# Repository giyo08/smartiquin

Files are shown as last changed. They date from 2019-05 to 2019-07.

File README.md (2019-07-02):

# Smartiquín
Proyecto para la cátedra SOA de la UNLaM

**Integrantes**

  * Alberto, Gisele Romina	   	34.154.196
  * Benítez, Gerardo Abel		    25.883.409
  * Coradini, Gonzalo Fabián		38.946.395
  * Vázquez, Lucia Maité	    	40.886.803

**Descripción**

Smartiquín es un botiquín de madera que te facilita la gestión de los medicamentos que estás tomando: ya que mantendrá un registro de los medicamentos, descontando la cantidad que se ingiere, te respalda diciendote si falta algún medicamento y te informará si hay demasiada humedad o luz dentro. Para todo esto, Smartiquín estará conectado a una aplicación móvil, en donde se podrá ver los datos de los medicamentos con los que se cuenta actualmente en el botiquín y las cantidades pertinentes. En la misma, se recibirán una serie de notificaciones para que el usuario esté informado en tiempo real del estado de sus medicamentos; las mismas notifican:
  * Cuando hay luz dentro del botiquín estando la puerta cerrada.
  * Cuando hay humedad en el mismo.
  * Cuando un medicamento está vencido.
  * Cuando de un medicamento hay pocas pastillas.
  * Cuando de un medicamento no hay más pastillas.
Además, el sistema cuenta con una apertura supervisada y segura: necesitarás la aplicación móvil para pedir que el botiquín se destrabe y puedas acceder a su contenido (necesitarás también la aplicación para hacer el bloqueo); de ésta forma, se restringe el acceso a los medicamentos al usuario de la aplicación, manteniéndolos fuera del alcance de los niños.

**Hardware a utilizar**

  * *Arduino UNO R3
  * *Protoboard de 150 puntos
  * *Sensor de humedad DHT11
  * *3 Switch fin de carrera
  * *Fotoresistor LDR
  * *Luces LED
  * *Módulo Bluetooth HC-05
  * *Buzzer activo
  * *Electroimán 12v
  * *Relay
  * *Cargador 5v
  * *Cargador 12v
  * *Cables de conexión
  * *Resistencias

**Software Utilizado**

Arduino IDE 1.8.9
Android Studio 3.4.1

**Descripción de la implementación**

El arduino y la aplicación móvil se comunicarán mediante bluetooth. En este caso utilizamos un módulo bluetooth para el arduino, de modelo HC-05.
Los medicamentos se colocarán arriba de los switchs, con los que se interpretará una ingesta de medicamento (una pastilla). 
El electroimán se mantendrá energizado de forma que trabe la puerta y, al mandarle una señal desde la aplicación, ya sea a través del respectivo botón o habilitando el shake del celular, el arduino desmagnetiza el imán destrabando la puerta. Para facilitar su implementación, utilizamos un relé para la interconexión entre arduino-electroimán.
En el botiquín habrá un sensor de luz y otro de humedad: el primero se colocará en el interior para determinar si dentro del botiquín cerrado hay presencia de luz, de modo que se pueda notificar al usuario cuando el botiquín no esté en condiciones. El segundo se colocará en el interior y se utilizará para efectivizar, cuando la humedad supere cierto valor apto, el envío de una notificación al usuario. Ambos, cuando tomen valores no deseados, activan la reproducción de un sonido de alerta con el buzzer. 
Los leds se dispondrán dos en el frente del botiquín, uno para informar si la puerta está cerrada - rojo- o abierta - verde-, y el restante, en el interior del botiquín para alumbrar el interior del mismo cuando el mismo esté abierto y en el ambiente no haya luz suficiente para ver los medicamentos.

**Manual de usuario**
 * Primeros pasos:

    * *Conexion Android-Smartiquín
    * *El usuario encenderá el Smartiquín.
    * *El usuario descargara e ingresara a la aplicación de Smartiquín en su dispositivo android (*).
    * *Debe permitir el encendido del bluetooth.
    * *A continuación deberá presionar “Conectar con Arduino”.
    * *Luego de unos segundos el Smartiquín estará conectado exitosamente con su dispositivo Android.

	(*) Versión mínima de android : android 6.0 MarshMallow

**Más información en:https://github.com/giyo08/smartiquin/blob/master/Informe-Final/Informe%20Final.pdf**

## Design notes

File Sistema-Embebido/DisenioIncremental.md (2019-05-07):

# Smartiquin: Diseño Incremental
Vamos a describir los diferentes pasos que recorrimos para llegar a la version final de nuestro prototipo

## Version 01: conexión basica, leds y pulsadores
Para la versión inicial vamos a usar como sensores algunos pulsadores, y variables preconfiguradas y como actuadores vamos a usar leds. 
En nuestra configuracion inicial usaremos

### Componentes: 
1. Servo = led rojo
2. Buzzer = Led azul
3. SensorHumedad = Variable
4. SensorLuz = SensorLuz
5. Switch01 = pulsador01
6. Switch02 = pulsador02
7. Switch03 = pulsador03

### Procedimiento 
Conexiones componente a componente
* LedRojo a PinDigital03
* LedAzul a PinDigital04
* Sensor de Luz a PinAnalogico01
* Pulsador01 a PinDigital07
* Pulsador02 a PinDigital08
* Pulsador03 a PinDigital09

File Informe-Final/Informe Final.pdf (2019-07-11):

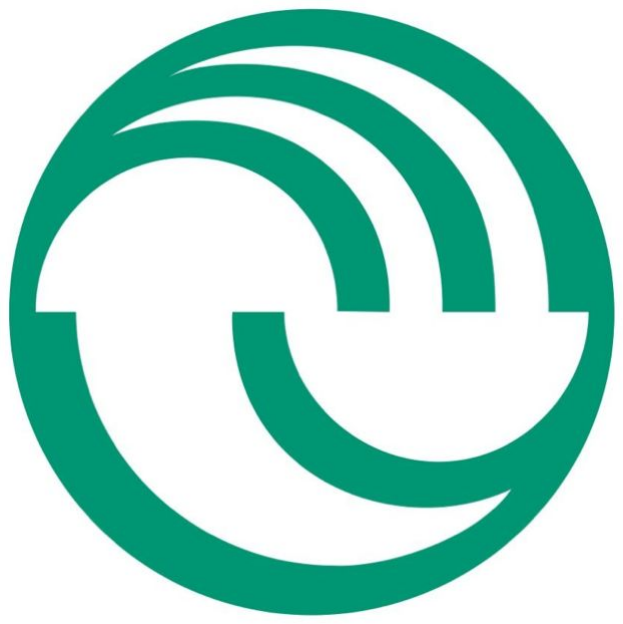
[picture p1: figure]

# UNLaM

# Sistemas Operativos Avanzados

2019

# SMARTIQUIN

## Sistemas Embebidos - Android

Profesores

- Barillaro, Sebastián
- Carnuccio, Esteban
- De Luca, Graciela
- García, Gerardo
- Valiente, Waldo A.
- Volker, Mariano

Integrantes

- Alberto, Gisele Romina | 34.154.196
- Benítez, Gerardo Abel | 25.883.409
- Coradini, Gonzalo Fabián 38.946.395
- Vázquez, Lucía Maité 40.886.803

Smartiquin | Sistemas Operativos Avanzados

Índice de Contenidos

Introducción | 2
Detalle de la Implementación | 2
Descripción | 2
Diseño Incremental | 3
Hardware Utilizado | 3
Software Utilizado | 4
Componentes | 4
Diagramas de bloques | 8
Diagrama de conexión | 10
Manual de usuario | 11
Android | 12
Activities: | 13
Sensores: | 14
Persistencia de datos: | 15
Conexión con el arduino: | 15
Fuentes | 15

## Introducción

Smartiquín es un botiquín de madera que te facilita la gestión de los medicamentos que estás tomando: ya que mantendrá un registro de los medicamentos, descontando la cantidad que se ingiere, te respalda diciendote si falta algún medicamento y te informará si hay demasiada humedad o luz dentro. Para todo esto, Smartiquín estará conectado a una aplicación móvil, en donde se podrá ver los datos de los medicamentos con los que se cuenta actualmente en el botiquín y las cantidades pertinentes. En la misma, se recibirán una serie de notificaciones para que el usuario esté informado en tiempo real del estado de sus medicamentos; las mismas notifican:

- Cuando hay luz dentro del botiquín estando la puerta cerrada.
- Cuando hay humedad en el mismo.
- Cuando un medicamento está vencido.
- Cuando de un medicamento hay pocas pastillas.
- Cuando de un medicamento no hay más pastillas.

Además, el sistema cuenta con una apertura supervisada y segura: necesitarás la aplicación móvil para pedir que el botiquín se destrabe y puedas acceder a su contenido (necesitarás también la aplicación para hacer el bloqueo); de ésta forma, se restringe el acceso a los medicamentos al usuario de la aplicación, manteniéndolos fuera del alcance de los niños.

## Detalle de la Implementación

## Descripción

El arduino y la aplicación móvil se comunicarán mediante bluetooth. En este caso utilizamos un módulo bluetooth para el arduino, de modelo HC-05.

Los medicamentos se colocarán arriba de los switchs, con los que se interpretará una ingesta de medicamento (una pastilla).

El electroimán se mantendrá energizado de forma que trabe la puerta y, al mandarle una señal desde la aplicación, ya sea a través del respectivo botón o habilitando el shake del celular, el arduino desmagnetiza el imán destrabando la puerta. Para facilitar su implementación, utilizamos un relé para la interconexión entre arduino-electroimán.

En el botiquín habrá un sensor de luz y otro de humedad: el primero se colocará en el interior para determinar si dentro del botiquín cerrado hay presencia de luz, de modo que se pueda notificar al usuario cuando el botiquín no esté en condiciones. El segundo se colocará en el interior y se utilizará para efectivizar, cuando la humedad supere cierto valor apto, el envío de una notificación al usuario. Ambos, cuando tomen valores no deseados, activan la reproducción de un sonido de alerta con el buzzer.

Los leds se dispondrán dos en el frente del botiquín, uno para informar si la puerta está cerrada - rojo- o abierta - verde-, y el restante, en el interior del botiquín para alumbrar el interior del mismo cuando el mismo esté abierto y en el ambiente no haya luz suficiente para ver los medicamentos.

## Diseño Incremental

Para la primera versión usamos 3 switchs como sensores y 3 leds, rojo, verde y blanco, como actuadores.

En esta etapa implementamos

- Switchs
- Leds

Aquí probamos encender y apagar los leds pulsando los switchs y funciono correctamente.

En un primer incremento añadimos el sensor de humedad DHT11.

En un segundo incremento agregamos un buzzer el cual probamos su funcionamiento con los pulsadores (que ya estaban implementados).

Como tercer incremento, incluímos el fotoresistor (sensor de luz).

A partir de aquí, agregamos al proyecto el electroimán el cual necesitaba un relé para controlarlo junto a una fuente de 12v (para el electroimán) y otra de 5v (para el relé).

Por último agregamos el módulo Bluetooth conectado a la fuente de 5v.

## Hardware Utilizado

Arduino UNO R3

Protoboard de 150 puntos

Sensor de humedad DHT11

3 Switch fin de carrera

Fotoresistor LDR

Luces LED

Módulo Bluetooth HC-05

Buzzer activo

Electroimán 12v

Relay

Cargador 5v

Cargador 12v

Cables de conexión

Resistencias

## Software Utilizado

Arduino IDE 1.8.9

Android Studio 3.4.1

## Componentes

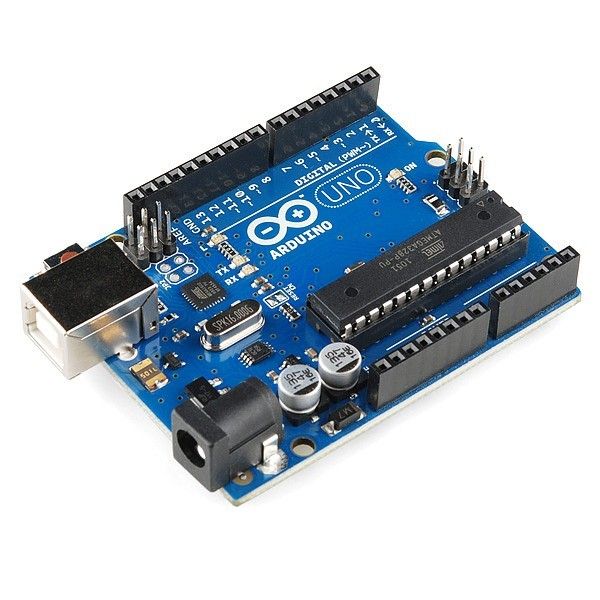
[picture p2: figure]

Arduino Uno

Arduino es una plataforma de prototipos electrónicos de código abierto basada en hardware y software flexibles y fáciles de usar. Arduino puede sentir el entorno mediante la recepción de entradas desde una variedad de sensores y puede afectar a su alrededor mediante el control de luces, motores y otros artefactos. Para programar el microcontrolador se utiliza el lenguaje de programación Arduino (basado en Wiring) y el software arduino (IDE).

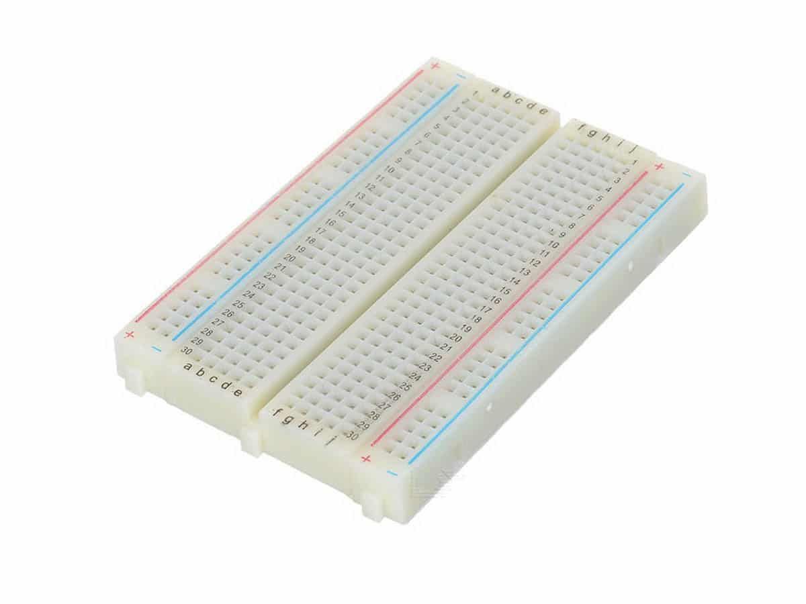
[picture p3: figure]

Protoboard

Tablero con orificios conectados eléctricamente entre sí de manera interna, en el cual se pueden insertar componentes electrónicos y cables para el armado y prototipado de circuitos electrónicos

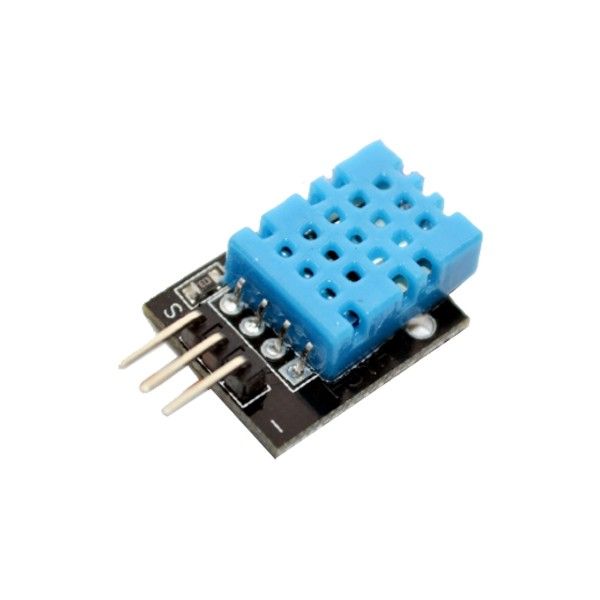
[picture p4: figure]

Sensor de humedad DHT 11

Sensor digital que nos permite medir la humedad relativa y la temperatura.

En Smartiquín es utilizado para medir la humedad dentro del botiquín.

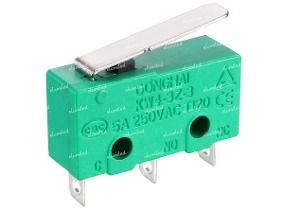
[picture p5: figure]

Switch final de carrera

Es un interruptor eléctrico que se acciona por muy poca fuerza física, a través del uso de un mecanismo de punto de inflexión, a veces llamado mecanismo de sobre-centro.

En Smartiquín es utilizado para controlar la cantidad y el estado de los medicamentos del botiquín.

Fotoresistor LDR

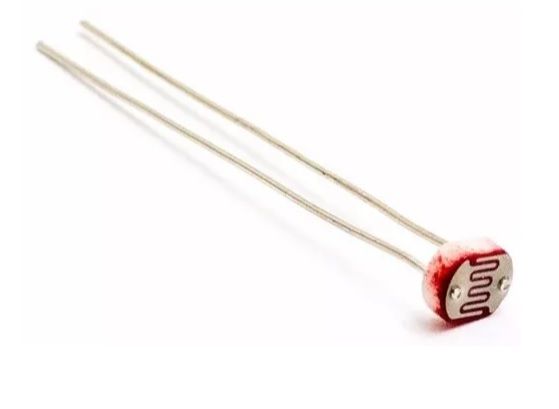
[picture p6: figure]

Componente cuya resistencia varía en función de la luz que recibe. Cuanto mayor sea la intensidad de luz que incide en la superficie del LDR menor será su resistencia y en cuanto menor sea la luz mayor será la su resistencia.

En Smartiquín es utilizado para comprobar que la luz del interior del botiquín no esté encendida cuando no sea necesario.

Luces led

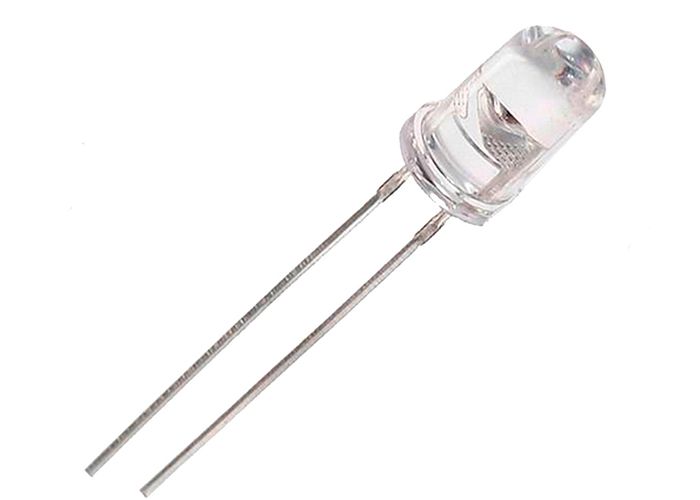
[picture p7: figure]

Es un componente electrónico de dos puntas que permite la circulación de energía a través de él en un solo sentido. Estos diodos LED son semiconductores y, cuando los electrones pasan a través de ellos, se convierten en luz.

En Smartiquín se utilizan para iluminar el botiquín y indicar el estado del botiquín (si se encuentra abierto o cerrado).

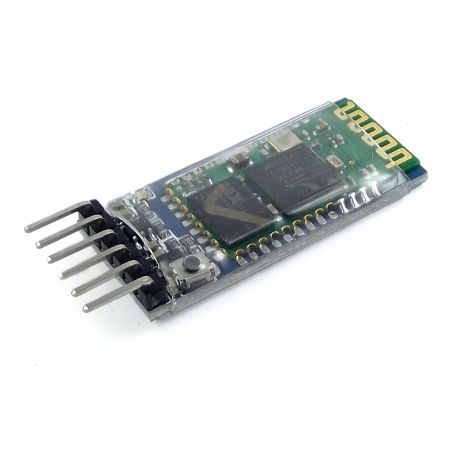
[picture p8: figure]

Módulo Bluetooth HC-05

El módulo bluetooth HC-05 viene configurado de fábrica para trabajar como maestro o esclavo. En el modo maestro puede conectarse con otros módulos bluetooth, mientras que en el modo esclavo queda a la escucha peticiones de conexión.

Este módulo bluetooth nos permite realizar un enlace inalámbrico entre el botiquín y un dispositivo Android, desde el cual controlaremos las características del Smartiquín.

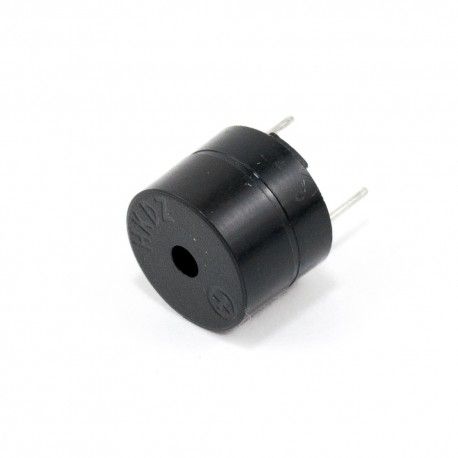
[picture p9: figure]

Buzzer Activo

Es un dispositivo que generan un sonido de una frecuencia determinada y fija cuando son conectados a tensión

En Smartiquín es utilizado para informar al usuario cuando el nivel de humedad del botiquín supera un rango máximo, como de informarle cuando no repuso los medicamentos en el botiquín.

Relay

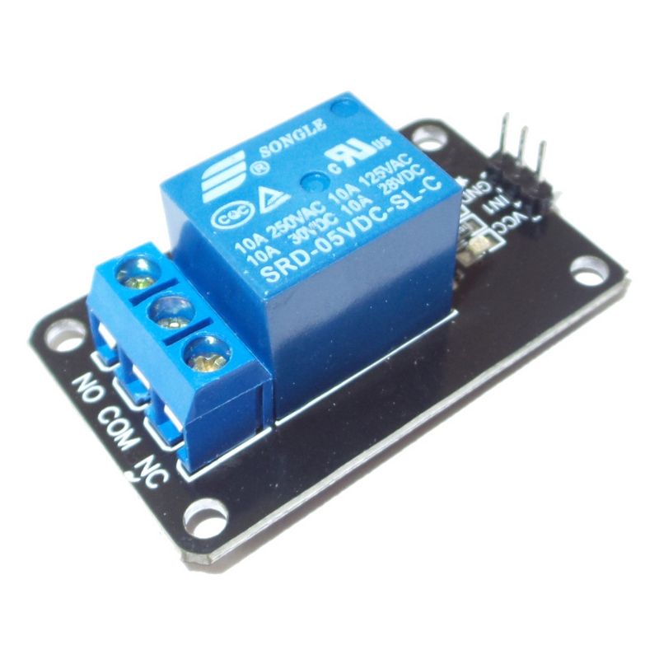
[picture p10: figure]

Dispositivo electrónico que se usa para el control o switcheo de cargas de potencia. Permite controlar el encendido y el apagado de cualquier aparato que se conecte a una fuente de alimentación externa. El relé hace de interruptor y se activa/desactiva mediante una entrada de datos. Gracias a esto se puede controlar el encendido de cualquier aparato.

En Smartiquín es usado junto a un electroimán para controlar el encendido y apagado de este.

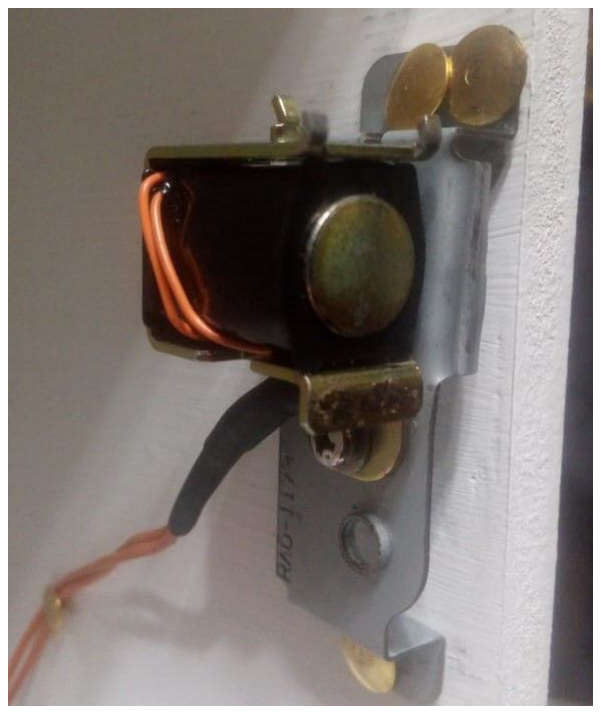
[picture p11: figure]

Electroimán

Dispositivo eléctrico que permite atraer objetos ferromagnéticos mediante el empleo de un campo magnético. Este puede ser encendido y apagado a voluntad, simplemente actuando sobre la corriente suministrada.

En Smartiquín es utilizado, junto a un relé, para bloquear y desbloquear la puerta del botiquín.

## Diagramas de bloques

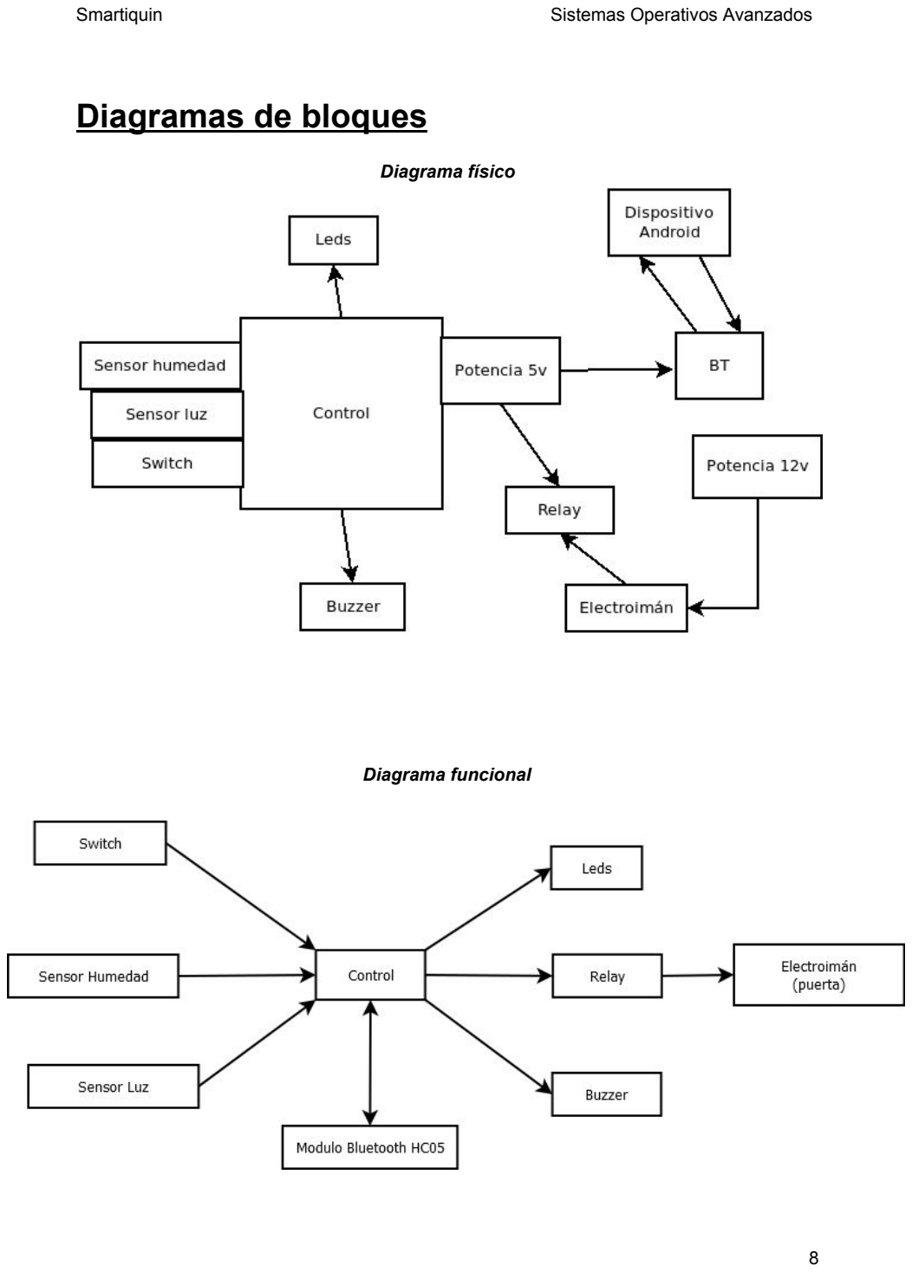
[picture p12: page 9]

Diagrama físico

Diagrama funcional

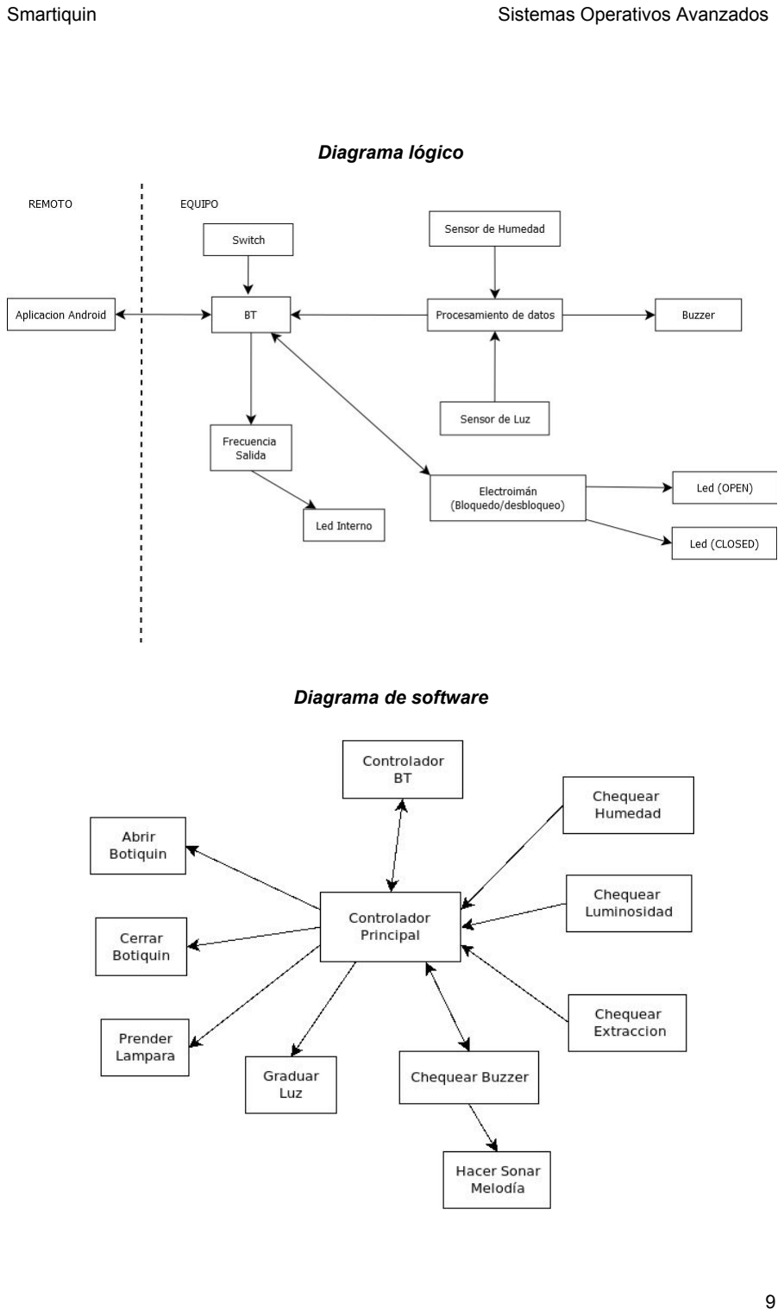
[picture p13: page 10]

Diagrama lógico

Diagrama de software

## Diagrama de conexión

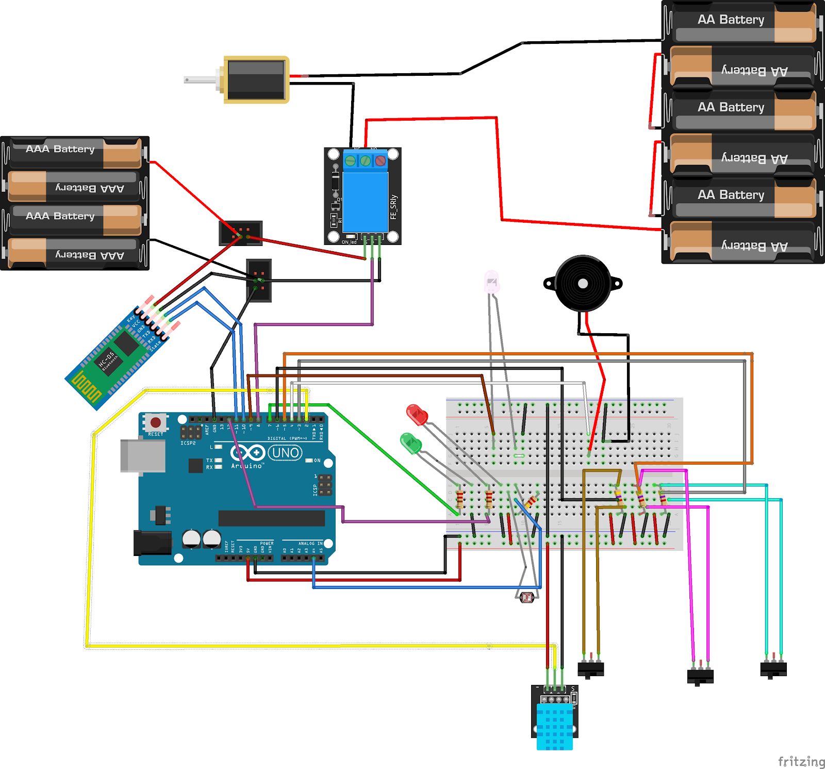
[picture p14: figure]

## Manual de usuario

Primeros pasos:

1) Conexion Android-Smartiquín
- El usuario encenderá el Smartiquín.
- El usuario descargara e ingresara a la aplicación de Smartiquín en su dispositivo android (*).
- Debe permitir el encendido del bluetooth.
- A continuación deberá presionar “Conectar con Arduino”.
- Luego de unos segundos el Smartiquín estará conectado exitosamente con su dispositivo Android.

(*) Versión mínima de android : android 6.0 MarshMallow

Eventos

1. Apertura/Cierre del botiquín
- Desde el dispositivo Android , el usuario deberá presionar el botón Abrir/Cerrar para abrir o cerrar el botiquín.
- Opcionalmente podrá optar por activar la apertura/cierre por shake (Agitar el celular).
- Activando esta opción, el usuario deberá agitar levemente el celular hacia cualquier lado.
- Cuando el movimiento sea considerado como una agitación, el dispositivo emitirá una vibración confirmando que la apertura/cierre del botiquín es correcta.
2. Ingreso de medicamentos
- En el botiquín, el usuario colocará el envase del medicamento en cualquiera de las tres posiciones disponibles (*).
- En la aplicación, el usuario deberá ingresar al registro de
medicamentos y agregar el medicamento colocado en el paso anterior.
- Ingresa al formulario donde ingresara:
- Posicion : Numero de slot en cual se colocó el medicamento.
- Nombre: Nombre del medicamento
- Laboratorio: Nombre del laboratorio del medicamento
- Fecha de Vencimiento: Fecha de caducidad del medicamento. Debe ser una fecha válida entre 2019 y 2039.

- Cantidad de Medicamentos: Cantidad de pastillas que se colocaron en el slot del botiquín.
- Cantidad Mínima: Cantidad límite en la cual se avisará al usuario en que debe reponer el medicamento.
- Una vez completado estos campos, se presiona “Aceptar” y el medicamento quedará registrado.

(*) Nota: Solo se tiene 3 posiciones para colocar el medicamento. Una vez completos estos slots no será posible controlar más medicamentos, aunque estos se encuentren en el botiquín.

3. Humedad elevada
- Al detectarse elevada niveles de humedad en el botiquín, este avisará al usuario encendiendo una alarma.
- Cuando esto ocurra, se activara un sensor de proximidad, de manera que el usuario podrá detener esta alarma acercando la mano al dispositivo android.
4. Luz encendida en el interior del botiquín
- Si ocurre que en el interior del botiquín, estando cerrado, hay presencia de luz, se notificará al usuario.
- Cuando esto ocurra, se activara un sensor de proximidad, de manera que el usuario podrá detener esta alarma acercando la mano al dispositivo android.

## Android

La aplicación en android ofrece una completa interacción y control con los medicamentos que se encontraran en el Smartiquín. Para esto se contará con registros que estarán asociados a los diferentes switch del botiquín. El usuario cargará los registros con la información de los medicamentos (como su nombre, laboratorio, fecha de vencimiento, cantidad de medicamentos), donde una vez registrado podrá ver su información y llevar un control de estos.

## Activities:

La aplicación cuenta con 3 activities las cuales son:

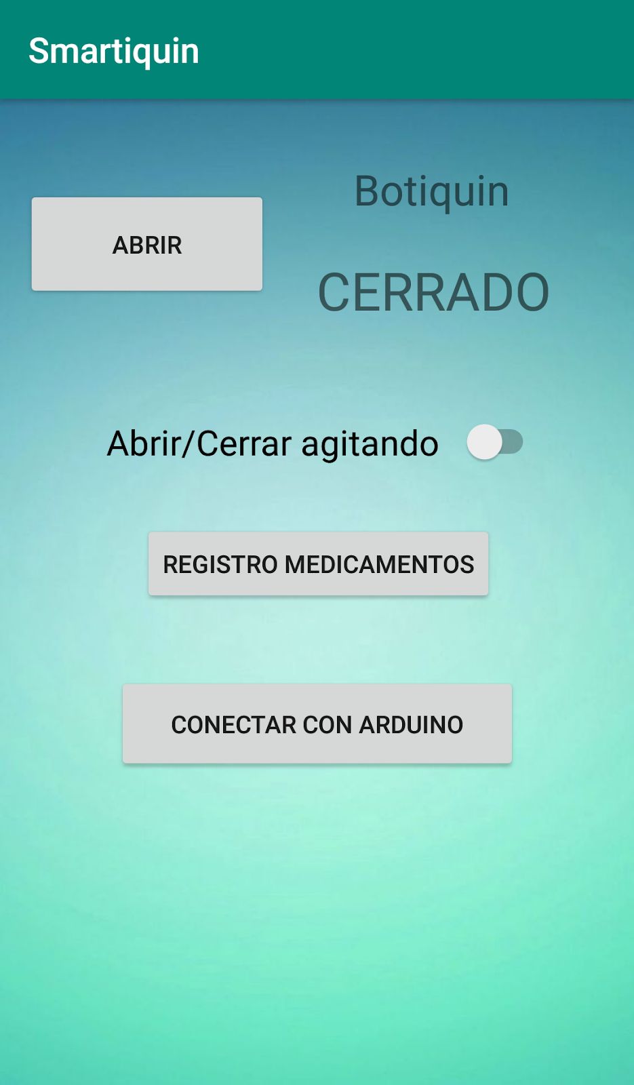
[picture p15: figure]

MainActivity

Activity principal en la cual se tiene las opciones de apertura del botiquín (Con un botón o con un shake), el acceso a los registros de medicamentos y la conexión con el arduino.

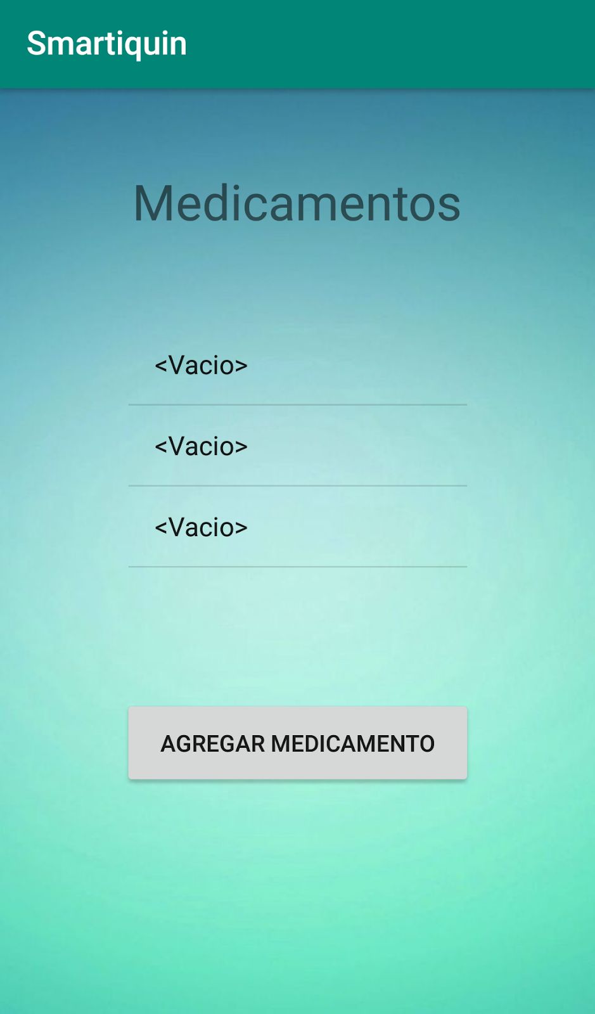
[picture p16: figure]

RegisterActivity

Activity en la cual tendremos la información de los medicamentos registrados que se encuentran en nuestro botiquín. Se podrá ver la información de los medicamentos registrados.

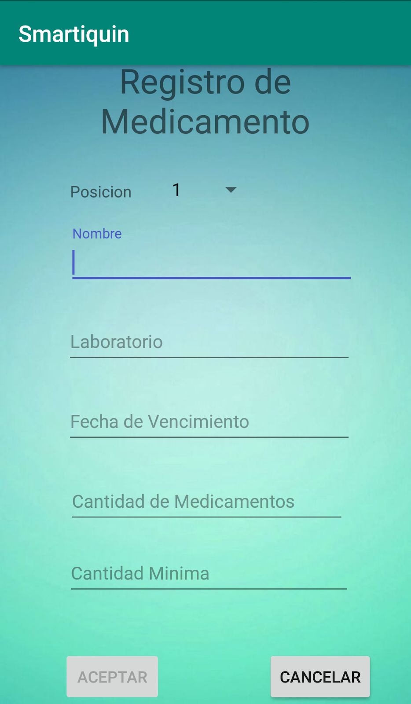
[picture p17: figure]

Form Activity

Activity en la cual se realiza el registro de la información de los medicamentos que se encuentran el botiquín.

## Sensores:

Para el funcionamiento de la aplicación utilizamos los siguientes sensores del dispositivo android:

Acelerómetro
Utilizando el acelerómetro logramos simular un shake con el cual, cuando el usuario active esta función, podrá abrir o cerrar el botiquín solamente agitando levemente el dispositivo android.

Para realizar esto, cuando se detecta un cambio en algunos de los tres ejes del dispositivo (X, Y, Z), verificamos si el valor obtenido sobrepasa un límite prefijado. Si lo hace este movimiento es tomado como una agitación y por lo tanto permite cambiar el estado del botiquín de abierto a cerrado o cerrado a abierto.

Sensor de luz
El sensor es utilizado para captar la luz presente en la habitación al momento de abrir el botiquín, de manera que si hay poca luz en la habitación se encenderá un led, dentro del botiquín, para iluminar su interior.

Sensor de proximidad
El sensor de proximidad entrará en acción al momento en que el buzzer, que se encuentra en el botiquín, comience a sonar debido a los factores a cual esté expuesto. En ese instante el sensor de proximidad se activará y el usuario podrá detener el sonido de alarma del botiquín aproximando la mano hacia el dispositivo android.

## Persistencia de datos:

Para conservar los registros de los medicamentos, ya que estos se perdían cuando la aplicación era detenida o destruida, optamos por elegir SQLite para conservar los datos en una base de datos que se encontrada en cada dispositivo android.

Cada registro es guardado en la base de datos, recuperado y actualizado dependiendo de la necesidad concreta de la aplicación en cada operación que se realice, manteniendo así la persistencia de los datos en nuestra aplicación.

## Conexión con el arduino:

La conexión entre el dispositivo Android y el Smartiquín es realizada mediante Bluetooth. El celular funciona como maestro y se conecta al módulo bluetooth que se encuentra en el arduino.

De esta manera podemos enviar la información necesaria entre el arduino y el dispositivo android.

## Fuentes

Arduino: https://www.arduino.cc/Android: https://developer.android.com/

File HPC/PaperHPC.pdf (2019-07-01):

## Reconocimiento Facial con OpenCV y OpenMP

Alberto Gisele Romina, Benitez Gerardo Abel, Coradini Gonzalo Fabián, Vázquez Lucia Maité

Universidad Nacional de La Matanza, Departamento de Ingeniería e Investigaciones Tecnológicas, Florencio Varela 1903 - San Justo, Argentina gisele.alberto08@gmail.com, gerardobenitez@gmail.com, gonzalocoradini@gmail.com, luciamaitev@gmail.com

Resumen. El siguiente documento es un trabajo de investigación donde analizaremos el funcionamiento del reconocimiento facial, su estado del arte y, a su vez, explicaremos la forma de implementación al proyecto Smartiquin. Para ello, aprovecharemos el poder de paralelización que ofrece OpenMP, para tener resultados en el menor tiempo posible, además de asegurar la correspondencia o no de la imagen capturada a través de la cámara IP, y contrastarlas con aquellas registradas en la base de datos.

Palabras claves: Reconocimiento Facial, Cámara IP, OpenCV, OpenMP.

### 1. Introducción

La investigación que se desarrolla en este documento está aplicada al sistema Smartiquin, donde buscamos añadir un método de seguridad alternativo para evitar accesos indeseados al mismo. El botiquín cuenta con una cerradura magnética que funciona mediante un electroimán como primera opción, y actualmente la apertura de la misma solo puede realizarse a través de una aplicación instalada en un smartphone. La segunda opción de apertura que vamos a agregar será mediante el reconocimiento facial, vamos a usar una cámara IP para capturar imágenes de los rostros frente al botiquín y mediante el algoritmo seleccionado, vamos a procesar las mismas utilizando threads para paralelizar la etapa de reconocimiento.
Uno de los desafíos es elegir el algoritmo adecuado para resolver la problemática de reconocimiento facial, debido a la dificultad de analizar los rasgos faciales en las imágenes captadas, existe variabilidad en la posición, iluminación, gestos, sombra, etc. Por último tomar ventaja de la paralelización de procesamiento ofrecida por la tecnología OpenMP con el fin de ofrecer resultados en un tiempo menor.
El reconocimiento facial es considerado como la medición biométrica más natural entre las que existen (huellas dactilares, lectura de iris, reconocimiento de voz, etc.), ya que es el método más utilizado por los seres humanos para reconocerse unos a otros. Aplicaciones como Google Fotos y Facebook, han incorporado el reconocimiento facial para distinguir a personas en tus fotos, y así poder etiquetarlas y clasificarlas. El iPhone X incorporó Face ID para autenticar usuarios [7]. En un uso más amplio, podemos ver la implementación del mismo en tiempo real en aeropuertos internacionales, o aquí en Buenos Aires, para identificar entre las personas que transitan por distintos lugares de Capital Federal, si están prófugos de la justicia, si es que se encuentran en la base de datos de personas buscadas en Argentina.

### 2. Desarrollo

Existen ocho algoritmos que pueden ser usados en reconocimiento facial [4] [5], que son: PCA, LDA, ICA, LBP, FDA, EBGM, KPCA, HMM, entre otros. Nosotros nos centraremos en el algoritmo PCA (Principal Components Analysis), ya que es un método matemático que se utiliza para reducir el número de variables, de forma que pasemos a tener el mínimo número de nuevas variables, llamadas componentes principales, y estos representan a todas las antiguas de la forma más representativa posible. En el caso puntual de reconocimiento facial, este algoritmo es llamado Eigenfaces[1], y funciona proyectando las imágenes faciales sobre un espacio de facciones que engloba las variaciones significativas entre las imágenes faciales conocidas.
[1]

Podemos dividir el proceso en dos módulos identificables: El módulo de inscripción, donde se lleva a cabo el registro del individuo a la base de datos (el entrenamiento del modelo), y el segundo es donde se realiza el reconocimiento a partir de los datos recolectados en el módulo anterior [2]. Dentro de nuestra investigación, utilizaremos librerías open source como OpenCV y OpenMP. La primera fue diseñada para procesamiento de imágenes, y entre las funcionalidades destacadas, se incluyen la detección y reconocimiento de objetos. OpenMP fue creada para soportar multiprogramación, por lo que es fundamental para trabajar con hilos concurrentes en la ejecución del algoritmo.

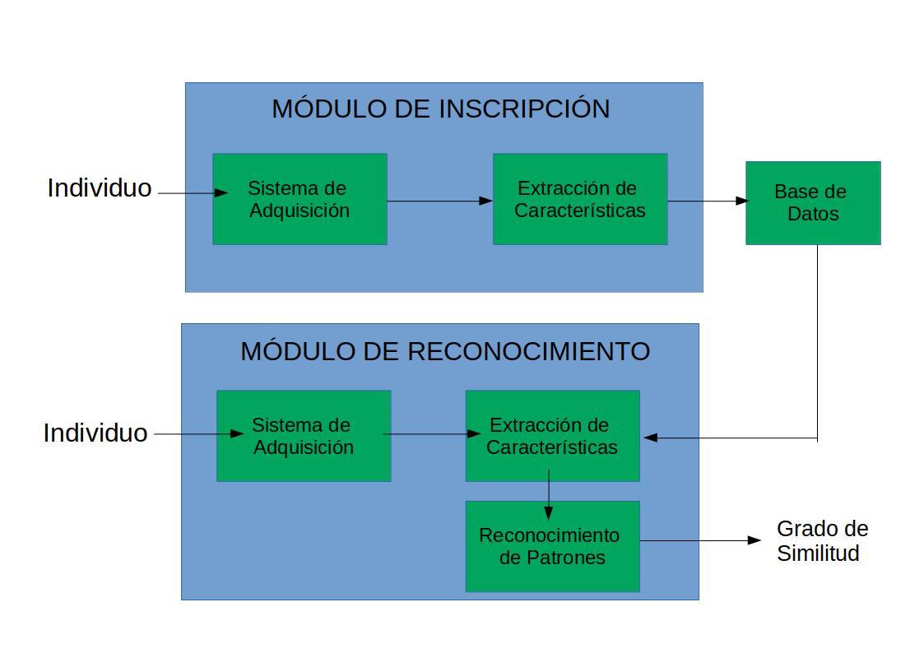
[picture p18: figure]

[2]

### Etapa de entrenamiento

Cómo primer paso, se debe detectar un rostro frente a la cámara ubicada en el botiquín, una vez ubicado, se dá lugar la detección de los ojos del sujeto dentro de esa región. Para obtener mejores resultados, es necesario que se tomen varias fotos por individuo, con distintas expresiones, y tomarse bajo condiciones equivalentes de iluminación. Estas se normalizan para alinear los ojos y la boca en todas las imágenes, y redimensionarlas a un tamaño común para todas de wxh pixeles. Esto se llevará a cabo cada vez que se registre un nuevo usuario en Smartiquin.
Una vez se tienen todas las imágenes de entrenamiento preprocesadas, se procede a la extracción de características, cuyo primer paso consiste en aplicar la técnica PCA al conjunto de imágenes preprocesadas para calcular los autovectores que formarán la base ortonormal del nuevo subespacio (Eigenfaces). Por último se proyectan las imágenes de entrenamiento preprocesadas sobre las eigenfaces, de tal forma que se obtienen los coeficientes de las imágenes de entrenamiento en el nuevo subespacio.

### Etapa de reconocimiento

Al igual que en la etapa de entrenamiento, algunos de los primeros pasos se repiten: Detectar el rostro y los ojos, luego realizar el preprocesado de la imagen captada. A partir de las eigenfaces ya calculadas, se proyectan cada uno de los rostros en el nuevo subespacio para obtener los coeficientes de las imágenes de estos rostros. Con estos nuevos coeficientes, más los previamente calculados en la etapa de entrenamiento, puede llevarse a cabo el reconocimiento. Para ello, con el teorema de Pitágoras, se calcula la distancia entre la proyección del rostro en cuestión y cada una de las proyecciones de las imágenes de entrenamiento. La proyección cuya distancia sea menor, indicará a qué individuo pertenece, y así proporcionar la autenticación deseada en nuestro proyecto.

### 3. Explicación del algoritmo

V_MIN depende del grado de coincidencia que deseemos tenga el algoritmo, 90% por ejemplo, para ser considerado válido.

registroUsuario() {
capturarImagen();
procesarImagen();
generarMatriz();
insertarEnBD();
}

reconocimientoUsuario() {
capturarImagen();
procesarImagen();
generarProyección();
if (compararCoeficientes() > = V_MIN) {
mostrarTexto(“Usuario Validado”); abrirBotiquin();
} else {

mostrarTexto(“Usuario No Registrado”); }

capturarImagen: Esta función va a contener los dos métodos que van a estar encargados de delimitar el recuadro de captura, y que servirán para el preprocesado de imágenes posterior.
- deteccionRostro: Esta función primeramente detectará la región del rostro,
utilizando | el | clasificador | Haas | proporcionados | en | OpenCV:
“haarcascade_frontalface”,
- deteccionOjos: Una vez detectada la región, pasará a realizar la detección de ambos ojos por separados con los clasificadores: “haarcascade_lefteye” y “haarcascade_righteye”. Conociendo la posición de los ojos, se puede llegar a determinar el ángulo de rotación de la cara para cuando se realice la alineación. procesarImagen: Aquí se aplican una serie de transformaciones a cada imagen detectada para la extracción de características, eliminando el pelo, orejas, y solo dejando visible el rostro. Posteriormente se aplica la rotación, el escalado, el recorte y la transformación a escala de grises. Se debe emplear el mismo tamaño para cada rostro ecualizado.
generarMatriz: Por simplicidad, englobamos en esta función la aplicación del algoritmo de PCA para obtener las Eigenfaces, generando los vectores correspondientes para las imágenes, y la matriz de covarianza. generarProyeccion: Aquí la imagen de prueba a ser procesada, se proyecta en un nuevo subespacio a partir de las Eigenfaces calculadas en generarMatriz, y se obtiene el coeficiente de ésta nueva imagen. compararCoeficientes: Es en esta función donde realizamos la paralelización con memoria compartida, lanzando hilos para que cada uno haga el reconocimiento simultáneamente, reduciendo el tiempo de ejecución. Se comparan los coeficientes de las proyecciones de las imágenes guardadas en la base de datos con las de la imagen captada.

### 4. Pruebas que pueden realizarse

Una de las pruebas que pueden realizarse, es la implementación del algoritmo con y sin el empleo de OpenMP, empleando una base de datos grandes, para así demostrar de forma certera, la diferencia en tiempos de ejecución al procesar las imágenes. Para este caso, utilizaremos alguna base de datos que esté en la nube, o creada por nosotros con un número considerable de individuos con sus variantes de imágenes.
Otra prueba, que podríamos realizar al emplear una cámara 3D, es verificar que si proporcionamos una fotografía de un usuario registrado frente a la lente, el sistema no valide el ingreso y avise de este evento, ya que una imagen plana no proporciona la misma profundidad que es capaz de detectar una cámara 3D.

### 5. Conclusiones

A modo de resumen, en este informe se propuso principalmente enunciar las consecuencias de incorporar el reconocimiento facial al sistema Smartiquin como método de seguridad adicional para la habilitación de la apertura del mismo, centrándonos en el algoritmo PCA - explicado en la sección 2. Gracias al mínimo número de nuevas variables que se consiguen con éste método matemático y al paralelismo en el procesamiento de las mismas, se logra una implementación eficiente del reconocimiento facial.
Si bien el algoritmo elegido es uno de los más usados, por robustez y facilidad de implementación, tiene sus desventajas en consideración a la luz ambiente y posición del rostro al querer realizar la identificación, por lo que en alguna futura investigación, podemos desarrollar el algoritmo de Fisherfaces, que si considera cambios de luz, posición y expresiones faciales.
A su vez, para futuras investigaciones, podríamos incorporar procesamiento GPU y ver cómo éste puede mejorar el desempeño de la paralelización.

### 6. Referencias

1. Lopez, E.: Estado del Arte del Reconocimiento Facial (2014)
2. Garduño Santana, M.A., Díaz-Sánchez, L. E. , Tabarez Paz, I., Romero Huertas, M.: Estado del Arte en Reconocimiento Facial (2017)
3. Arcos Acuña, Y.F., Moreno Meneses, D.A., Niño Pacheco, W.D.: Prototipo de Seguridad Mediante Reconocimiento Facial por Medio del Algoritmo de Eigenfaces (2015)
4. Dominguez Pavón, S.: Reconocimiento Facial Mediante el Análisis de Componentes Principales (PCA) (2017)
5. Suryaprasad, J., Sandesh, D. S., Priyanka, I., Pravalika, G.N., Aman Kumar: Parallel Implementation and Performance Evaluation of Facial Recognition Algorithms Using Open Source Technologies (2017)
6. Aprende Machine Learning https://www.aprendemachinelearning.com
7. Gemalto https://www.gemalto.com/latam/sector-publico/biometria/reconocimiento-facial

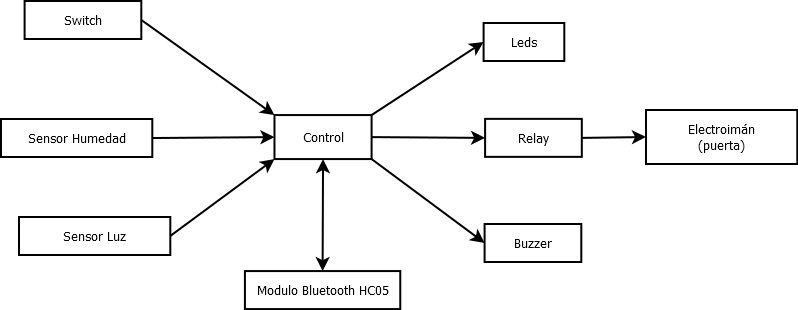
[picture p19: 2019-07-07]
Sistema-Embebido/Diagramas/DiagramaFuncional.png

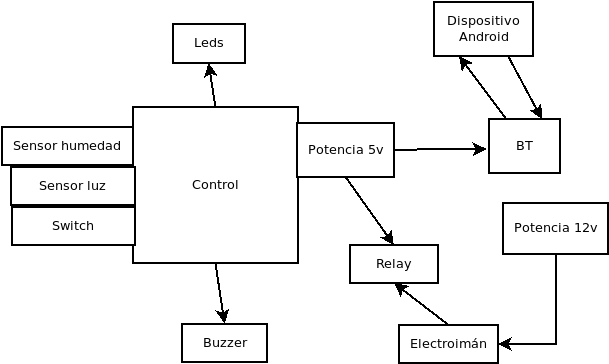
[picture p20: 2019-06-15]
Sistema-Embebido/Diagramas/DiagramaFisico.png

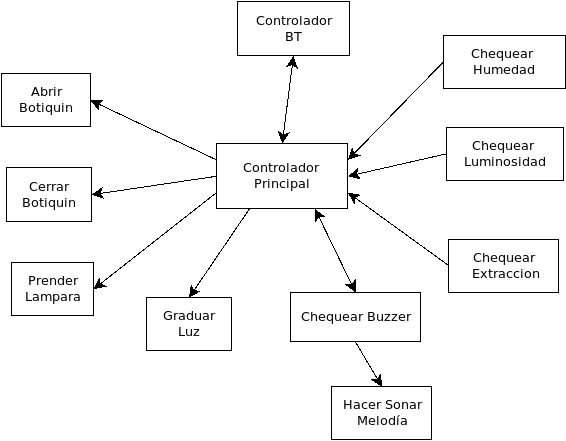
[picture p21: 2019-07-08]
Sistema-Embebido/Diagramas/DiagramaSoftware.png

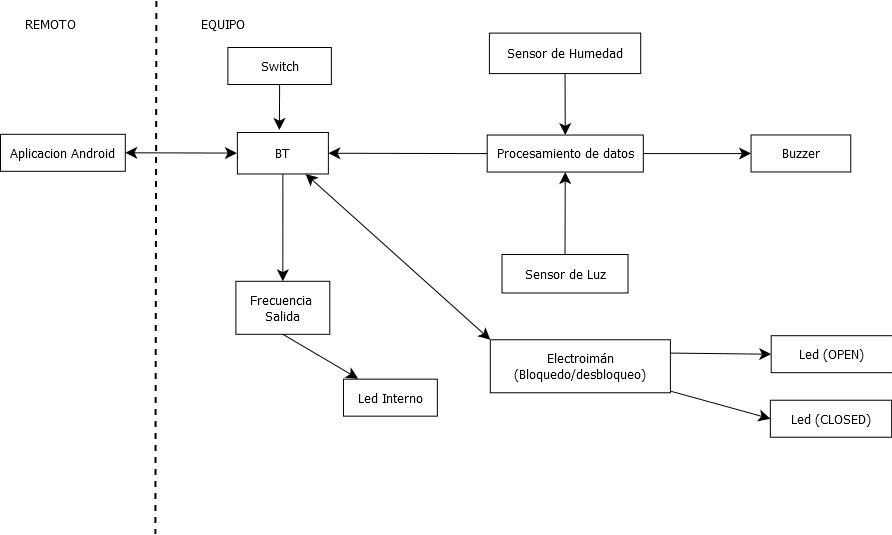
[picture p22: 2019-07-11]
Sistema-Embebido/Diagramas/DiagramaLogico.png

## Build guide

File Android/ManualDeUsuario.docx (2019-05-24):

MANUAL DE USUARIO

Smartiquin te permite guardar tus medicamentos de manera segura, y avisarte cual debe tomar de acuerdo al momento del día.

Aplicación Android:

Al iniciar la aplicación, se verá un dashboard con información actualizada sobre humedad y temperatura dentro del botiquín, y tres botones con opciones para realizar las siguientes acciones: Registrar Medicamentos, Desbloquear Botiquín. y Bloquear Botiquín.

Desde la opción de Registrar Medicamentos, se cargan los datos de aquellos que el usuario utiliza, indicando en cada uno si la ingesta se realiza por la mañana o por la noche. Esto permitirá al sistema avisarle si está próxima la toma de determinado medicamento.

Si posee un celular con escáner de huellas, ingresando a la opción Desbloquear Botiquín, se debe validar la huella digital antes de abrir la puerta del mismo. Al seleccionar la opción Validar Huella Digital, se comparará con aquella que el usuario tenga registrada en el celular; si no es correcta se pedirá validar de nuevo, y si corresponde a la guardada, se habilitará el botón Abrir.

Si el usuario no posee un celular con escáner de huellas, la opción Abrir estará habilitada por defecto para que del mismo modo pueda destrabar la puerta.

La opción Bloquear Botiquín, vuelve a trabar el cerrojo al cerrar la puerta del botiquín.

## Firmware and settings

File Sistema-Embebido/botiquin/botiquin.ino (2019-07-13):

#include <SoftwareSerial.h>
#include <DHT.h>

// Constantes de interpretación de comunicación BT

#define PARAR_ALARMA 'L'
#define ABRIR_PUERTA 'A'
#define CERRAR_PUERTA 'C'
#define LAMPARA_APAGADA 'P'
#define LAMPARA_PRENDIDA_A_MEDIAS 'T'
#define LAMPARA_PRENDIDA 'Z'
#define HUMEDAD_ELEVADA 'H'
#define LUZ_ELEVADA 'L'
#define SWITCH3_DESACTIVADO '3'
#define SWITCH2_DESACTIVADO '2'
#define SWITCH1_DESACTIVADO '1'
  
/*
 * Sensores y actuadores asociados
 */
 
byte switch01 = 3; 
byte switch02 = 5;
byte switch03 = 6;
byte buzzer = 4;
byte LED_Green = 7;
byte LED_Red = 12;
byte lampara = 9;
byte electroiman = 8;
byte DHTpin = 2;
byte RX = 10;
byte TX = 11; 

byte fotoresistor = A4;

SoftwareSerial Bt1(RX, TX);



/*
 * Sensor Temperatura y Humedad
 */
 
#define DHTTYPE DHT11 // Declaramos el modelo de sensor a utilizar
DHT dht(DHTpin, DHTTYPE); // Inicializamos la variable de comunicación entre el sensor y Arduino


/*
 *  Variables
 */

char digitoLeidoBT = ' ';
float valorLuminosidadLeido;

boolean puertaAbierta = true;

// Relacionadas con los switchs

boolean switch1SinPulsarRecientemente = true; // Variable de control de corte
boolean switch2SinPulsarRecientemente = true; // Variable de control de corte
boolean switch3SinPulsarRecientemente = true; // Variable de control de corte

// Relacionadas con el sensor de luz

const int LUMINOSIDAD_MAX = 800; // luminosidad máxima admitida dentro del botiquín
boolean luzNoPermitidaRecientemente = true; // Variable de control de corte

// Relacionadas con el sensor de temperatura y humedad

const byte HUMEDAD_MAX = 80; // humedad máxima permitida dentro del botiquín
boolean humedadNoPermitidaRecientemente = true; // Variable de control de corte
float humedadLeida;

unsigned long tiempo_anterior_lecturaHumedad = 0;
const unsigned long INTERVALO_LECTURA_HUMEDAD = 5000;

// Relacionadas al tiempo y las esperas

unsigned long tiempo = 0;
unsigned long tiempo_anterior = 0;
const unsigned long INTERVALO_LOOP_PRINCIPAL = 200;

// Relacionadas con la alarma

boolean alarmaApagada = false;
boolean alarmaDeHumedad = false;
boolean alarmaDeLuz = false;
boolean alarmaApagadaRecientemente = true; // Variable de control de corte
unsigned long tiempoAlarmaFueApagada;
const unsigned long INTERVALO_ALARMA_SIN_SONAR = 10000; // en milisegundos



void setup() {
  pinMode(buzzer, OUTPUT);
  pinMode(electroiman, OUTPUT);
  pinMode(lampara, OUTPUT);
  pinMode(LED_Green, OUTPUT);
  pinMode(LED_Red, OUTPUT);
  pinMode(switch01, INPUT);
  pinMode(switch02, INPUT);
  pinMode(switch03, INPUT);
  pinMode(DHTpin, INPUT);
  

  cerrar_botiquin();
  Serial.begin(9600);
  Bt1.begin(9600); 
  dht.begin();
}


/*
 * ******************** FIN DE DECLARACIONES ********************
 * ******************** COMIENZO DEL PROGRAMA *******************
 */

/**
   Determina el tiempo que se tomara entre un cheque de estados
   y otro.
*/
bool intervalo_cumplido() {
  return ((tiempo - tiempo_anterior) > INTERVALO_LOOP_PRINCIPAL);
}

/**
   Determina si se cumplio un intervalo particular de tiempo,
   compara un tiempo inicial y previo contra un tiemp de espera
   Parametros:
   - actual: es el tiempo actual
   - previo: es el tiempo tomado antes de iniciar el proceso a controlar
   - espera: es la cantidad de tiempo que debe transcurrir para indicar si se
   cumplio el intervalo
*/
bool intervalo_particular_cumplido(unsigned long actual, unsigned long previo, unsigned long espera) {
  return ((actual - previo) > espera);
}

/*
 * ******************** HUMIDITY CONTROL ZONE *******************
 */

/**
   Chequea que la humedad no exeda los rangos minimos y maximos. 
   En caso contrario, notifica al disposivo movil y suena una alarma.
*/
void chequear_humedad() {
  humedadLeida = dht.readHumidity();
  
  if (isnan(humedadLeida) ) {
    Serial.println("Falló al leer del sensor DHT");
  } else if ( humedadLeida > HUMEDAD_MAX ) {
      
      if( humedadNoPermitidaRecientemente ){
        Bt1.write(HUMEDAD_ELEVADA);
        humedadNoPermitidaRecientemente = false;
        alarmaDeHumedad = true;
      }

  }else{
    alarmaDeHumedad = false;
    humedadNoPermitidaRecientemente = true;
  }
 
}


/*
 * ******************** LIGHT CONTROL ZONE *******************
 */

/*
    Chequea que no haya luz en el interior del botiquín cuando éste esté
    cerrado. Si hay luz dentro, manda un mensaje, notificando al celular, y hace sonar la alarma.
*/
void chequear_luminosidad() {
  valorLuminosidadLeido = analogRead(fotoresistor);

   
  if ( !puertaAbierta && valorLuminosidadLeido > LUMINOSIDAD_MAX ){
    if( luzNoPermitidaRecientemente){
      Bt1.write(LUZ_ELEVADA);
      luzNoPermitidaRecientemente = false;
      alarmaDeLuz = true;
    }
   
  } else{
    alarmaDeLuz = false;
    luzNoPermitidaRecientemente = true;
  }
}


/*
 * En la aplicación de android tendríamos que mandar por msj el nivel de luz que querémos, y acá directamente llamar a esta función
 * con el porcentaje requerido de luz.
 * Como no tiene resistencia, el 100% tendria que ser 128.
 * 255 es el 100% del voltaje proporcionado.
 * 128 es la mitad, en este caso 2,5v
 * 
 */
void prender_lampara(int porcentaje){
  int i = (porcentaje*128/100);
  analogWrite(lampara, i);
}


/*
 * ******************** DOOR CONTROL ZONE *******************
 */

void cerrar_botiquin(){
  /*Activar rele*/
  digitalWrite(electroiman, HIGH);
  /*Encender led rojo*/
  puertaAbierta = false;
  cambiar_estado_puerta();
  hacer_sonar_melodia();
}

void abrir_botiquin() {
  /*Desactivar rele*/
  digitalWrite(electroiman, LOW);
  /*Encender led verder*/
  puertaAbierta = true;
  cambiar_estado_puerta();  
  hacer_sonar_melodia();
}

void cambiar_estado_puerta(){
   if( !puertaAbierta ){
        digitalWrite( LED_Red, HIGH);   
        digitalWrite( LED_Green, LOW);
        digitalWrite(lampara, LOW);
   }
   else{
        digitalWrite( LED_Green, HIGH);
        digitalWrite( LED_Red, LOW);
   }
}


/*
 * ******************** SWITCH CONTROL ZONE *******************
 */

 
/**
  Este metodo se usa para identificar que alguno de los switch
  han sido desactivados, es decir, se tomo la caja de medicamentos
  de uno de los slots
*/
void chequear_extraccion() {
  actuar_switch01();
  actuar_switch02();
  actuar_switch03();
}

void actuar_switch01() {
    byte switchPulsado = digitalRead(switch01); //1 => pulsado | 0 => no pulsado
    if(!switchPulsado){ //se sacó el medicamento 
      if( switch1SinPulsarRecientemente ){ //primera vez que entra al loop de switch sin pulsar
        switch1SinPulsarRecientemente = false;
        /*
         * informo a la aplicación que se sacó algo
         */
          Bt1.write(SWITCH1_DESACTIVADO);
      }   
    }
    else{ // el switch3 esta pulsado
      switch1SinPulsarRecientemente = true;
    }
}



void actuar_switch02() {
    byte switchPulsado = digitalRead(switch02); //1 => pulsado | 0 => no pulsado
    if(!switchPulsado){ //se sacó el medicamento 
      if( switch2SinPulsarRecientemente ){ //primera vez que entra al loop de switch sin pulsar
        switch2SinPulsarRecientemente = false;
        /*
         * informo a la aplicación que se sacó algo
         */
          Bt1.write(SWITCH2_DESACTIVADO);
      }   
    }
    else{ // el switch3 esta pulsado
      switch2SinPulsarRecientemente = true;
    }
}

void actuar_switch03() {
    byte switchPulsado = digitalRead(switch03); //1 => pulsado | 0 => no pulsado
    if(!switchPulsado){ //se sacó el medicamento 
      if( switch3SinPulsarRecientemente ){ //primera vez que entra al loop de switch sin pulsar
        switch3SinPulsarRecientemente = false;
        /*
         * informo a la aplicación que se sacó algo
         */
          Bt1.write(SWITCH3_DESACTIVADO);
      }   
    }
    else{ // el switch3 esta pulsado
      switch3SinPulsarRecientemente = true;
    }
}


/*
 * ******************** BUZZER ZONE *******************
 */

void chequear_buzzer(){
  if(!alarmaApagada && (alarmaDeHumedad || alarmaDeLuz))
    hacer_sonar_melodia();
  else{ //se apago la alarma 
    if(alarmaApagadaRecientemente){
      tiempoAlarmaFueApagada = tiempo;
      alarmaApagadaRecientemente = false;
    }
    if(intervalo_particular_cumplido(tiempo, tiempoAlarmaFueApagada, INTERVALO_ALARMA_SIN_SONAR)){
      alarmaApagada = false;
      alarmaApagadaRecientemente = true;
    }
  }
}

/**
 * La idea de esta función ahora fue hacerla generica, despues solo tendría que ponerse
 * las llamadas a la función directamente.
  */
  
 void hacer_sonar_melodia() {
    noTone(buzzer);
    tone(buzzer, 1915);
}

/*
 * ******************** CONTROL ZONE *******************
 */

void loop(){
  
  tiempo = millis();

  if(intervalo_particular_cumplido(tiempo, tiempo_anterior_lecturaHumedad, INTERVALO_LECTURA_HUMEDAD)){
    chequear_humedad();
    tiempo_anterior_lecturaHumedad = tiempo;    
  }

  if ( intervalo_cumplido() ) {
    
    chequear_luminosidad();
    chequear_extraccion();
    chequear_buzzer();
    
    if(Bt1.available()){ /// te dice si hay algo en el buffer
      digitoLeidoBT = Bt1.read();
      
        /*
         * LOGICA DE INTERPRETACIÓN
         */
      Serial.println("Mensaje recibido: " + digitoLeidoBT );

         
      if(digitoLeidoBT == PARAR_ALARMA){ 
         alarmaApagada = true;
         
      }else if( digitoLeidoBT== ABRIR_PUERTA){ 
        
         abrir_botiquin();
         
      }else if( digitoLeidoBT == CERRAR_PUERTA){ 
         cerrar_botiquin();
         
      }else if( digitoLeidoBT == LAMPARA_APAGADA){ 
         prender_lampara(0);
         
      }else if( digitoLeidoBT == LAMPARA_PRENDIDA_A_MEDIAS){ 
         prender_lampara(50);
         
      }else if( digitoLeidoBT == LAMPARA_PRENDIDA){ 
         prender_lampara(100);
      }
    }
    
    tiempo_anterior = tiempo; 
  }
}

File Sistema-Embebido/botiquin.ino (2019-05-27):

// pines digitales
byte switch01 = 3;
byte switch02 = 4;
byte switch03 = 5;
byte humedad01 = 13;
byte LED_Red01 = 7;
byte LED_Blue01 = 11;
byte servo01 = 11; //en principio se trata de un led azul
byte buzzer01 = 11; 
byte pulsador01 = 12; //Por ahora deshabilitado
byte ldr01 = A4;

//parametros
int MINUTO = 60000;
int TIEMPO_CHEQUEO = 2 * MINUTO;
byte HUMEDAD_MIN = 20;
byte HUMEDAD_MAX = 90;
byte LUMINOSIDAD_MIN = 10;
byte LUMINOSIDAD_MAX = 70;

int abierto = 0;
int cerrado = 1;
int pulsado = 1;
int encendido = 1;
int apagado = 0;
int abrir_pestillo = 0;

//relacionadas al tiempo y las esperas
unsigned long tiempo = 0;
unsigned long tiempo_anterior = 0;
unsigned long intervalo = 200;

/**
   Determina el tiempo que se tomara entre un cheque de estados
   y otro.
*/
bool intervalo_cumplido() {
  return ((tiempo - tiempo_anterior) > intervalo);
}

/**
   Determina si se cumplio un intervalo particular de tiempo,
   compara un tiempo inicial y previo contra un tiemp de espera
   Parametros:
   - actual: es el tiempo actual
   - previo: es el tiempo tomado antes de iniciar el proceso a controlar
   - espera: es la cantidad de tiempo que debe transcurrir para indicar si se
   cumplio el intervalo
*/
bool intervalo_particular_cumplido(unsigned long actual, unsigned long previo, unsigned long espera) {
  return ((actual - previo) > espera);
}

/**
   Esta funcion obtiene los valores minimos y maximos de cada
   parametro a comprobar, se comunica con un microservicio
   que le sirve los valores actualizados
*/
void obtener_parametros_externos() {
  //conectarse y obtener valores
}

void setup() {
  // put your setup code here, to run once:
  pinMode(servo01, OUTPUT);
  pinMode(pulsador01, INPUT);
  pinMode(buzzer01, OUTPUT);
  //digitalWrite(pulsador01, HIGH);
  Serial.begin(9600);


  obtener_parametros_externos();
}


/**
   Chequea que la humedad no exeda los rangos minimos y maximos
   caso contrario, actua en consecuencia llamando a los actuadores
   correspondientes.
*/
void chequear_humedad() {
  //Si excede el valor maximo activar buzzer
  int valorHumedad = digitalRead(humedad01);
  if (valorHumedad > HUMEDAD_MAX) {
    //activar_buzzer();
  }
};

/**
   Chequea que la luminosidad no exeda los rangos minimos y maximos
   caso contrario, actua en consecuencia llamando a los actuadores
   correspondientes
*/
void chequear_luminosidad() {};

void encender_apagar_led(byte led, int veces) {
  unsigned long t_actual;
  unsigned long t_previo = 0;
  unsigned long interval = 750;
  int cumplidas = 0;
  int estado_proximo;
  while (cumplidas < veces + 1) {
    t_actual = millis();
    if ( intervalo_particular_cumplido(t_actual, t_previo, interval) ) {
      Serial.print("\n*************** Intervalo cumplido, PRENDER*************");
      estado_proximo = !digitalRead(led);
      digitalWrite(led, estado_proximo);
      t_previo = t_actual;
      if (estado_proximo == encendido) {
        cumplidas++;
      }
    }
  }
  digitalWrite(led, LOW);

}

/**
   Funcion que enciende el buzzer para que emita sonido por una determinada cantidad
   de tiempo
   Parametros:
   - tiempo: es la cantidad de tiempo en milisegundos que debe permanecer encendido el buzzer
*/
void encender_buzzer(int tiempo) {
  unsigned long t_actual;
  unsigned long t_previo = 0;
  unsigned long interval = 350;
  int cumplidas = 0;
  int estado_proximo;
  
  t_actual = millis();
  digitalWrite(buzzer01, HIGH);
  if ( intervalo_particular_cumplido(t_actual, t_previo, interval) ) {
    digitalWrite(buzzer01, LOW);  
  }  
}



int ledApagado(byte led) {
  return digitalRead(led) == 0;
}


void actuar_switch01() {
  byte switchPulsado = digitalRead(switch01);
  if (switchPulsado && ledApagado(LED_Blue01)) {
    encender_apagar_led(LED_Blue01, 1);
  }
}


void actuar_switch02() {
  byte switchPulsado = digitalRead(switch02);
  if (switchPulsado && ledApagado(LED_Blue01)) {
    encender_apagar_led(LED_Blue01, 2);
  }
}

/**
  Este metodo se usa para identificar que alguno de los switch
  han sido desactivados, es decir, se tomo la caja de medicamentos
  de uno de los slots
*/
void chequear_extraccion() {
  //actuar_switch01();
  //actuar_switch02();
}

/**
   Realiza la apertura de una puerta, es decir llama a actuar al servomotor
   para que mueva un pestillo
*/
void chequear_apertura() {
  if (abrir_pestillo == 1) {
    digitalWrite(servo01, HIGH);
    //abrir_pestillo = 0;
  } else {
    digitalWrite(LED_Blue01, LOW);
  }
}



void chequear_pulsador() {
  //int v_ldr = digitalRead(pulsador01);
  delay(50);
  int v_pulsador = digitalRead(pulsador01);
  if ( v_pulsador == HIGH and digitalRead(servo01) == LOW ) {
    //abrir_pestillo = 1;
    digitalWrite(servo01, HIGH);

  } else {
    //abrir_pestillo = 0;
    digitalWrite(servo01, LOW);
  }
  Serial.print("\nvalor pulsador: ");
  Serial.print(v_pulsador);

}


void loop() {
  // put your main code here, to run repeatedly:
  tiempo = millis();
  if ( intervalo_cumplido() ) {
    //chequear_humedad();
    //chequear_luminosidad();
    //chequear_extraccion();
    //chequear_pulsador();
    //chequear_apertura();
    chequear_encender_buzzer();
    tiempo_anterior = tiempo;
  }
}

void chequear_encender_buzzer(){
  byte switchPulsado = digitalRead(switch01);
  if (switchPulsado) {
    tone(buzzer01, 550, 2000); 
  }
}

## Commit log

2019-04-19 agregado de integrantes e info sobre idea inicial en readme
2019-04-19 edits para readme
2019-04-20 Creacion de carpetas
2019-04-22 agrego codigo base para embebido
2019-04-22 Update README.md
    Acomodé algunas oraciones para que sea más legible
2019-04-26 elimino funcionalidad para sensor de temperatura, incorporo funciones para switch
2019-05-07 primera version del disenio incremental
    [botiquin_luces_y_pulsador.fzz]
2019-05-07 modificacion readme y agregado diagrama de software
2019-05-12 Creacion de proyecto y prueba Huella dactilar
2019-05-14 Agrego 2 de los 3 switches y los programo para que por cada pulsacion enciendan un led segun el numero de switch
2019-05-21 agregado de labels de texto
2019-05-21 cambio de servo por electroiman
2019-05-21 manual de usuario v1
2019-05-25 agrego libreria dht11 y funcion de chequeo de humedad
2019-05-25 Re-versionado Android , eliminacion lector de huella
2019-05-25 Kotlin malo
    sal de mi proyecto
2019-05-26 Agregado Funcionalidad Abrir/Cerrar con shake
    Uso de sensor acelerometro
2019-05-26 Correccion Shake y Agregado Sensor de proximidad
2019-05-27 cambios para agregar pruebas con buzzer
    [botiquin.ino]
2019-05-28 agrego funcionalidad para manejo de modulo bluetooth y llamar a las funciones correspondientes segun comando recibidos
2019-05-29 ajustes al sketch de arduino para 2 leds, 3 switchs, un buzzer y un ldr
    [botiquin.ino]
2019-05-30 Actualizo sketch y elimino funciones que ya no uso
2019-06-05 movimiento de archivos y modificacion del .gitignore
2019-06-06 Bloqueo a pantalla vertical y sensor de luz
2019-06-10 BD para medicamentos y cambios activity Registros
2019-06-10 Cambios Activity Register
    Agregado info de cada elemento
    Boton eliminar
2019-06-10 Cambios Activity Registros
    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
2019-06-11 Agrego list para elegir switch
    Ahora se puede elegir el switch desde el formulario de cargar medicamentos
2019-06-13 Arreglo de querys
2019-06-17 Inicio la conexión por bluetooth desde el arduino
2019-06-17 Enviar/Recibir datos desde Android a arduino
2019-06-22 cambios conexiones arduino
2019-06-24 Add files via upload
    Agrego diagramas de conexión
    [DiagramaDeConexion.fzz]
2019-06-30 Borrado de codigo comentado
2019-07-03 diagramaDeConexionConCorrecciones
    Tenía un pin mal conectado
    [DiagramaDeConexion.fzz]
2019-07-06 Correccion de lo anterior
2019-07-06 Corrección de la corrección
2019-07-06 Correccion conexion³
    espero que funcione
2019-07-13 Mejoras en el uso de la aplicacion, verificacion de conexion y amigabilidad de mensajes
2019-07-13 Agrego constantes para mejorar legibilidad
2019-07-13 actualizacion de constantes
2019-07-13 correccion de mensaje
